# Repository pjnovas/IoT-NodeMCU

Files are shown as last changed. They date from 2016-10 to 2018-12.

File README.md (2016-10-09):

# IoT-NodeMCU

### Features
* Reads temperature and humidity
* Show current state in a 16x2 Display
* Allows to switch on/off 2 outlets from HTTP POST over wifi
* Expose an API at root when connected to Wifi returning a JSON with the current state
* Posting state to another webserver at a period of time
* Expose NodeMCU GPIOs for future plug-ins (like other sensors)
* Outside buttons for Reset and Flash without the need for opening the box

### What's in this repo?
* `arduino`: Arduino code for ESP8266 ESP-12F NodeMCU v2.0
* `electronics`: Schema, components and modules list
* `box`: 3D design of the clousure and STL files for 3D Printing

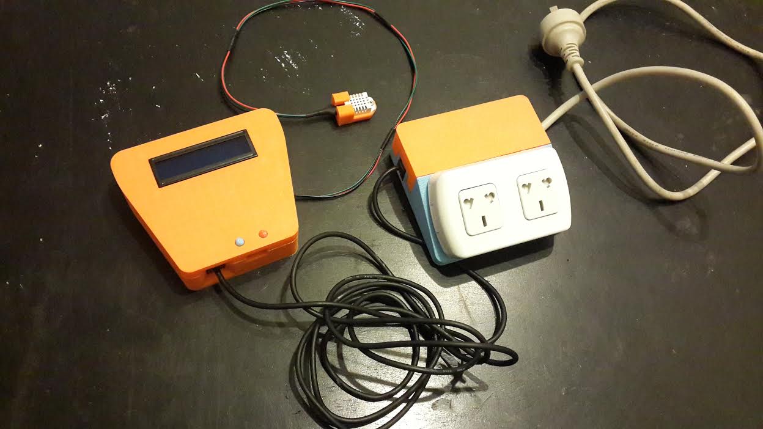
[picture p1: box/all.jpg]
box


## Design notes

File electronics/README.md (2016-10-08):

## Components
* Capacitor Polarized	3300uf 10v
* 10kΩ Resistor
* 2x RJ11 Female

## Modules
* ESP8266 WiFi ESP-12F - NodeMCU v2.0
* DHT22 Humidity and Temperature Sensor	
* I2C PCF8754
* Display Lcd 1602 HD44780 16x2
* 2 Relay Module - 5v to 220v 10A

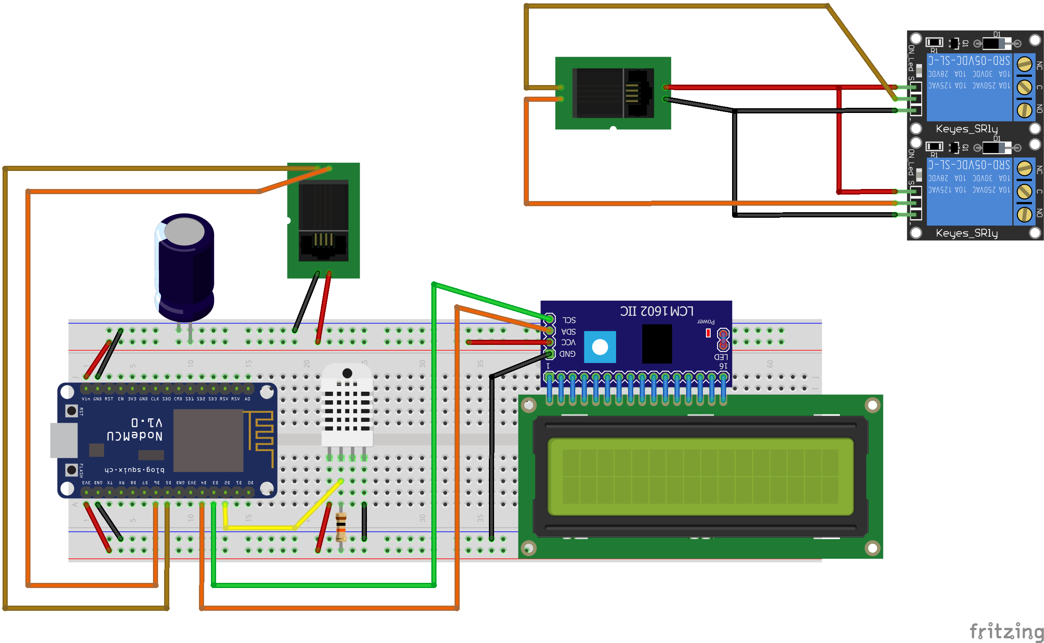
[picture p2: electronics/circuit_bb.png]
protoboard


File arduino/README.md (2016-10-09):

# Getting Started

1. Download and install [Arduino IDE](https://www.arduino.cc/en/Main/Software) 1.6.8+
2. Open Arduino IDE with the code inside iot_nodemcu dir
3. Add support to ESP8266 > follow [this guide](https://learn.sparkfun.com/tutorials/esp8266-thing-hookup-guide/installing-the-esp8266-arduino-addon)
4. Install  [LiquidCrystal_I2C](https://github.com/marcoschwartz/LiquidCrystal_I2C) library:
  1. Download repo as zip file
  2. Open Arduino IDE > Sketch > Include Library > Add .zip Library
5. Install [DHT Sensor](https://github.com/adafruit/DHT-sensor-library) library (same steps as before)
6. Copy `iot_nodemcu/_a_config.ino` into `iot_nodemcu/a_config.ino` and uncomment the code.
7. Set your configs defaults are set for pins as are described in the `electronics` directory
8. Compile the code

## Uploading code
1. Plug by USB the NodeMCU
2. Choose at Tools > Board > NodeMCU 1.0 (ESP-12E Module)
2. Set the correct port at Tools > Port
3. Press and hold FLASH button (RED on this box)
4. Press once RESET button (Blue on this box) - keep holding FLASH button
5. Click Upload code at Arduino IDE (without releasing FLASH)
6. It will compile and then when it starts uploading (showing uploading dots) > release FLASH button

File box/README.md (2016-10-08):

It is divided in 2 module boxes, one for the electronics and other for the 2 relays and 2 power outlets  
These modules are connected by a telephone cable (RJ11) 4 cables: VDC (5v), GND, R1, R2

## Electronics Module
Holds the perfboard and the display. It uses:
* 3 screws of 2.5mm x 6mm (to attach perfboard to the base)
* 4 screws of 3mm x 9mm (to close the box)

## Power Module
Holds the 2 relay module and the outlets. It uses:
* 4 screws of 2.5mm x 6mm (to attach the 2 relay module to the base)
* 4 screws of 3mm x 9mm (to close the box)
* 4 screws of 3mm x 9mm (to attach outlets on the box)

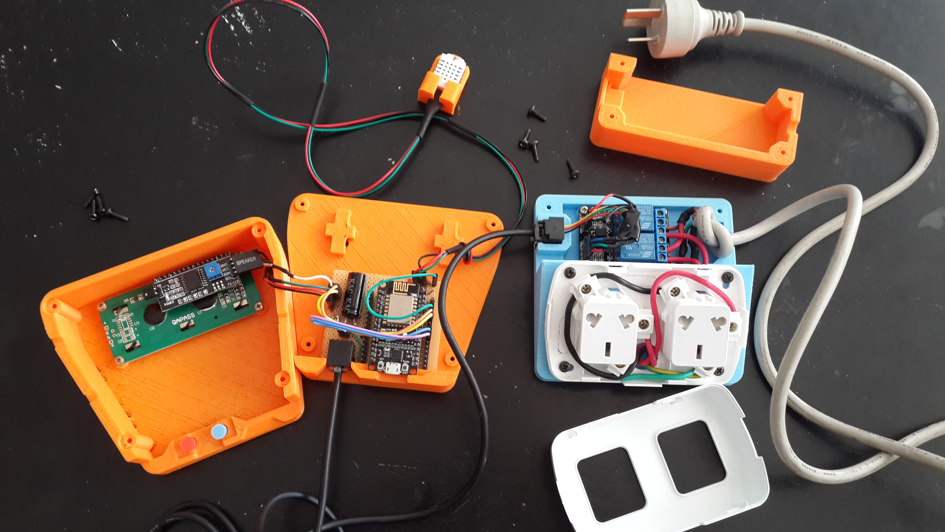
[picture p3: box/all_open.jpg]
all


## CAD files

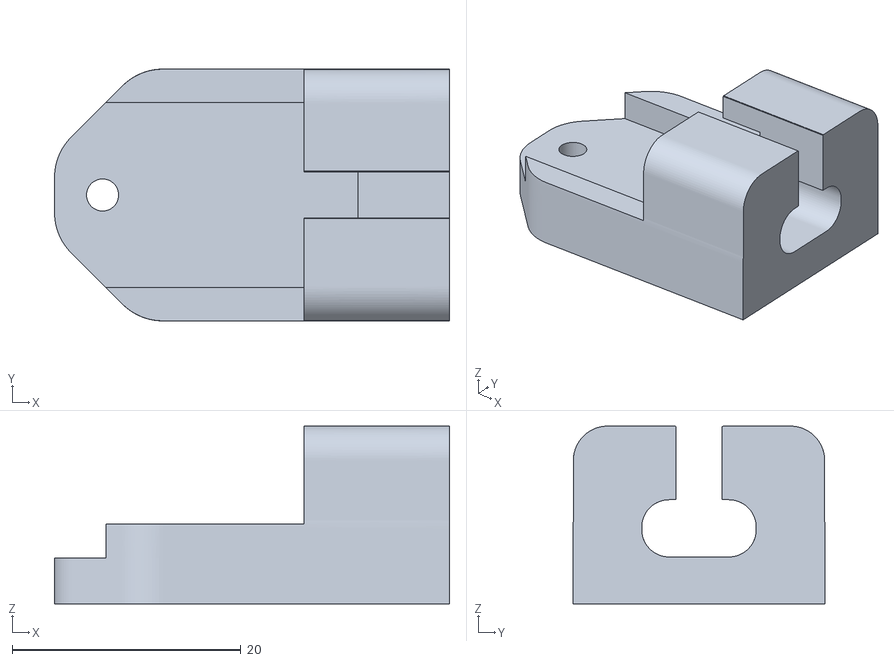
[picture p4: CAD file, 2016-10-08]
box/sensor_holder.stl
34.5 x 22.0 x 15.5

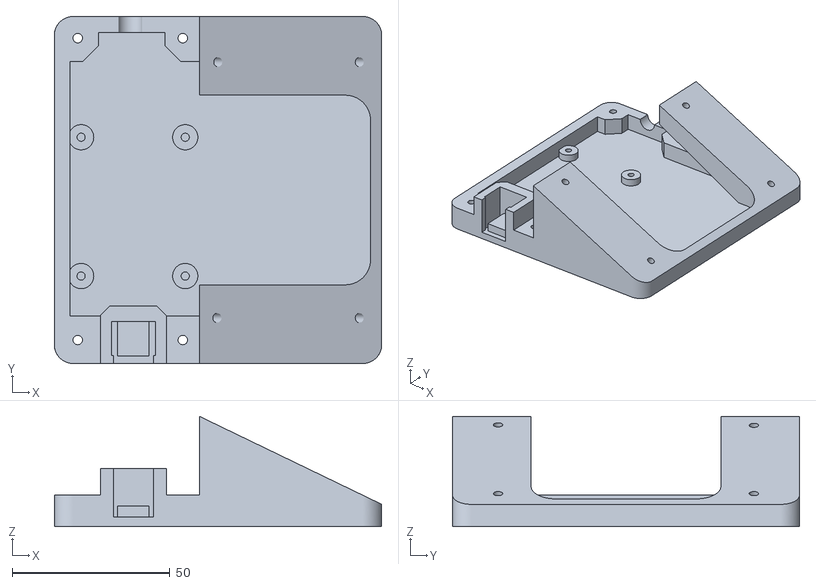
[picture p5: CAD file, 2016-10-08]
box/power_base.stl
103.8 x 110.0 x 35.0

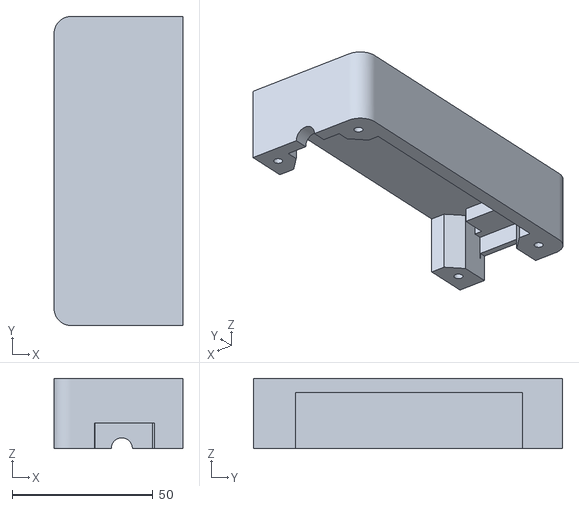
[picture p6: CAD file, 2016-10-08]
box/power_top.stl
45.8 x 109.9 x 25.0

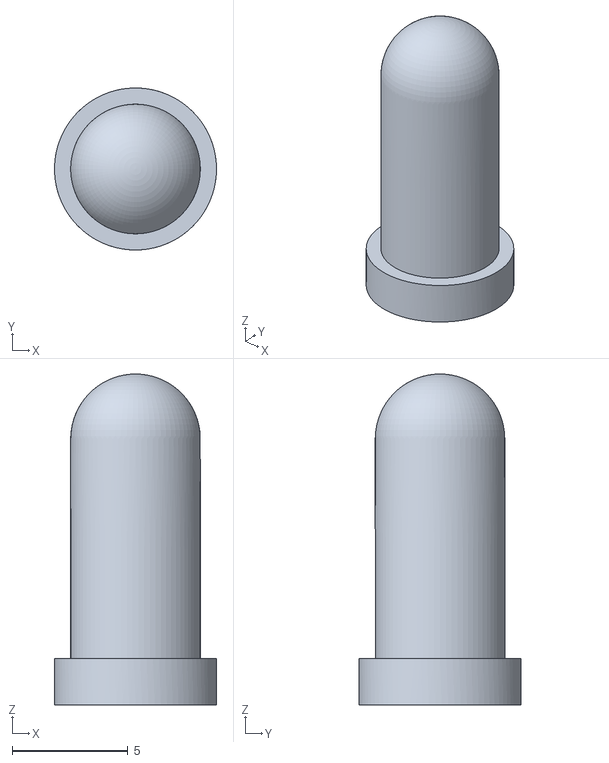
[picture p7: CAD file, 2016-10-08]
box/button.stl
7.00 x 7.00 x 14.3

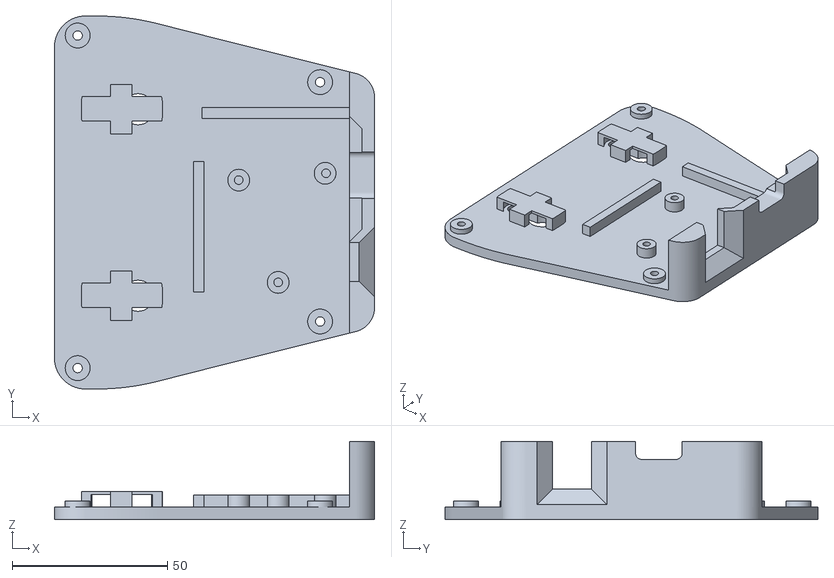
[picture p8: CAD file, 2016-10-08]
box/box_base.stl
103.0 x 120.0 x 25.1

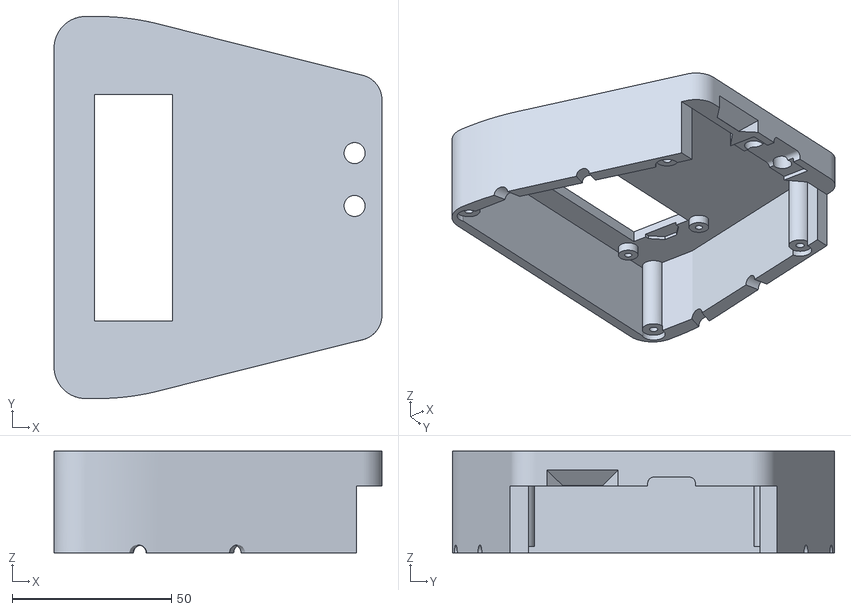
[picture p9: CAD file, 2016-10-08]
box/box_top.stl
103.0 x 120.0 x 32.0

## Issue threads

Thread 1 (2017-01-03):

Case for 20×4 I2C LCD

vstoms, 2017-01-03:
Hi,

Great project, is there a option to get a box to fit a 20×4 I2C LCD?

pjnovas, 2017-01-06:
hey, so I think that could work, but not sure since the inner box is pretty tight for the MCU and the LCD of 16x2, you could give it a try with the stl but I have really no time right now to check that out, sorry.

If you do so please ping me or send a PR it would be a nice-to-have 👍

Closed 2017-01-06.

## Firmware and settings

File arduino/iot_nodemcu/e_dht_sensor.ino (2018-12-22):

#include <DHT.h>

#define DHTTYPE DHT22
#define DHTPIN  D2 // Pin for Sensor

DHT dht(DHTPIN, DHTTYPE, 11);

unsigned long dht_previousMillis = 0;       // will store last temp was read

void read_temperature() {
  float _humidity, _temp_c, _hi_c;
  unsigned long currentMillis = millis();

  if(currentMillis - dht_previousMillis >= globalConfig.refreshRate) {
    dht_previousMillis = currentMillis;

    _humidity = dht.readHumidity();
    _temp_c = dht.readTemperature();

    if (isnan(_humidity) || isnan(_temp_c)) {
      #ifdef DEBUG
        Serial.println("Failed to read from DHT sensor!");
      #endif
      return;
    }

    humidity = _humidity;
    temp_c = _temp_c;

    updateLCDState();

    #ifdef DEBUG
      Serial.println("READ DHT sensor OK!");
    #endif
  }
}

void setupSensor() {
  dht.begin();
}

void loopSensor() {
  read_temperature();
}

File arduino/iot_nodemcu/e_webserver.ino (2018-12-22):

#include <ESP8266WebServer.h>
#include <ArduinoJson.h>

ESP8266WebServer server(80);

String getJSON() {
  return "{\"temperature\":"+toString(temp_c)+",\"humidity\":"+toString(humidity)+",\"r1\":"+r1+",\"r2\":"+r2+"}";
}

void responseJSON(String json) {
  server.send(200, "application/json", json);
  delay(100);
}

void responseJSON(String json, int statusCode) {
  server.send(statusCode, "application/json", json);
}

void setupWebServer() {
  server.on("/", [](){ 
    responseJSON(getJSON()); 
  });
  
  server.on("/r1/on", HTTP_POST, [](){ toggleR1(true); server.send(204); delay(100); });
  server.on("/r1/off", HTTP_POST, [](){ toggleR1(false); server.send(204); delay(100); });

  server.on("/r2/on", HTTP_POST, [](){ toggleR2(true); server.send(204); delay(100); });
  server.on("/r2/off", HTTP_POST, [](){ toggleR2(false); server.send(204); delay(100); });

  server.on("/eeprom", HTTP_GET, [](){ 
    responseJSON(getEEPROMJSON()); 
  });
  
  server.on("/eeprom", HTTP_POST, [](){ 
    StaticJsonBuffer<200> jsonBuffer;
    JsonObject& root = jsonBuffer.parseObject(server.arg("plain"));

    if (!root.success()) {
      responseJSON("{\"error\": \"malformed request body\"}", 400);
      return;
    }

    #ifdef DEBUG
      Serial.print("refreshRate: ");
      Serial.println(root["refreshRate"].as<int>());
    #endif

    int refreshRate = root["refreshRate"].as<int>();
    if (refreshRate < 1000) {
      responseJSON("{\"error\": \"refreshDate must be greater than 1000\"}", 400);
      return;
    }
    
    globalConfig.refreshRate = refreshRate;
    
    saveEPROM();
    
    server.send(204); 
    delay(100); 
  });

  server.begin();

  #ifdef DEBUG
    Serial.println("HTTP server started");
  #endif
}

void loopWebserver() {
  server.handleClient();
}
